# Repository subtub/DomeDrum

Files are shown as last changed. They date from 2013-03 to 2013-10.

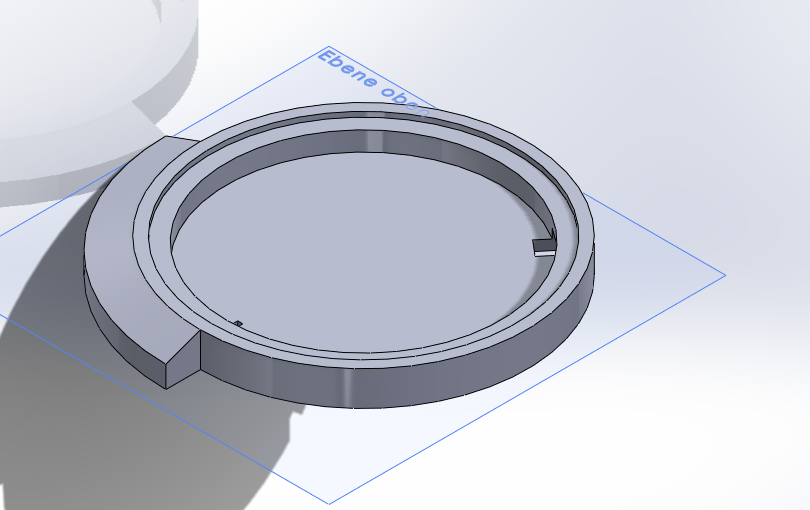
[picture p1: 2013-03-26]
Images/base_side_view.PNG

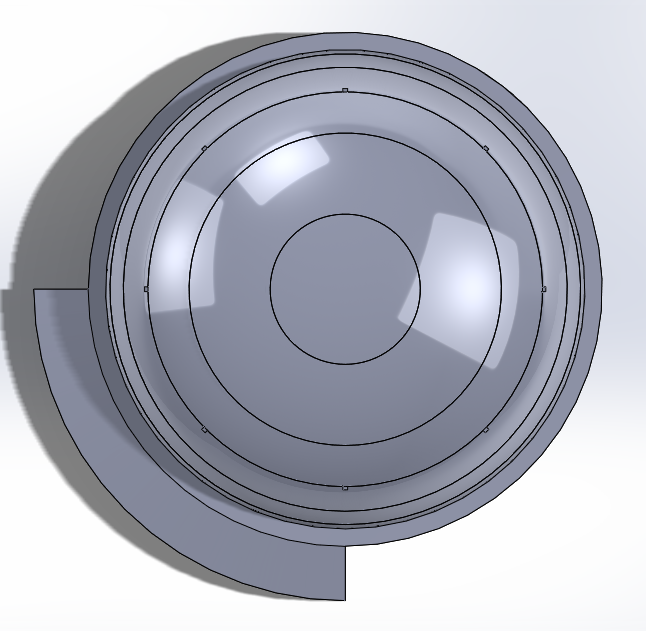
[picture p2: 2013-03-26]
Images/complete_top_view.PNG

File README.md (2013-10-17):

# DomeDrum

DomeDrum body image

**DomeDrum** is an open source MIDI controller.

Our aim of making the first version of **DomeDrum** was building a drum controller which feels like an analog drum. Did you ever play a [Djembe](http://en.wikipedia.org/wiki/Djembe)? It has one surface, depending on where you hit it the sound differs. We like pad-based controllers like the [MPC](http://en.wikipedia.org/wiki/Music_Production_Center), too but it's far away from an anlog drum. We wanted to brings that analog feeling back.

# DIY

We used an additional »head« made out of silicone on top of the wooden body for a softer feel while drumming. Use whatever you think feels good here.
To asseble your own DomeDrum you need to mill the wooden body, assemble the electronics and upload our Arduino software to a [Teensie Board](http://www.pjrc.com/teensy/).
Have a look at the [shopping list](https://github.com/subtub/DomeDrum/blob/master/Shopping_List.md) to see what's needed.

Bitdeli Badge (https://bitdeli.com/free "Bitdeli Badge")

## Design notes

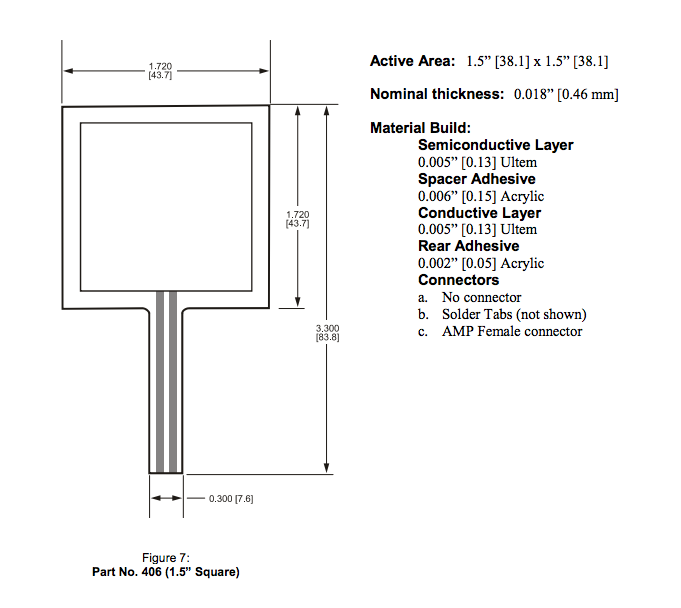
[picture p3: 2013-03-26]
Images/fsr-406_dimensions.png

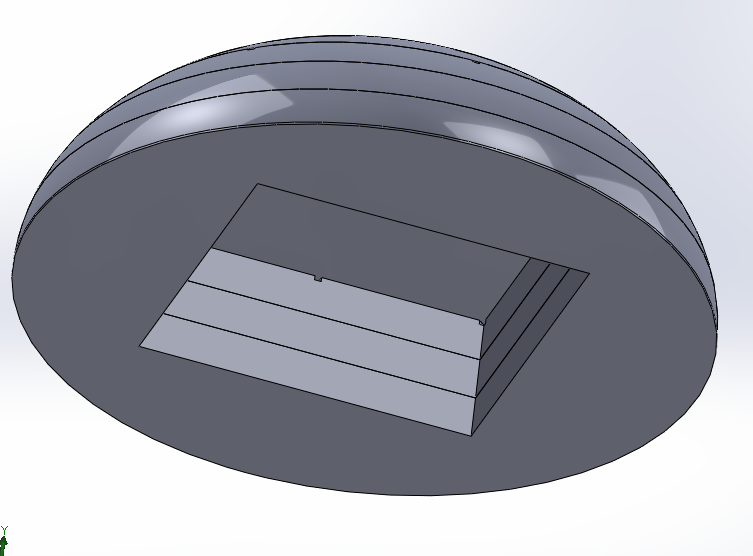
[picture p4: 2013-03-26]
Images/dome_bottom_view.PNG

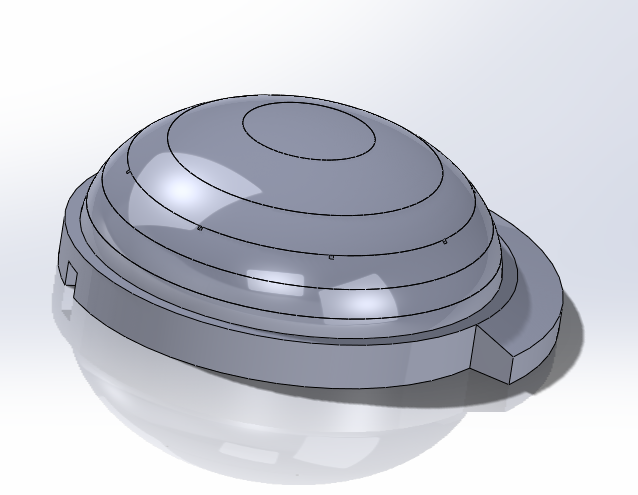
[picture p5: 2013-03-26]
Images/complete_side_view.PNG

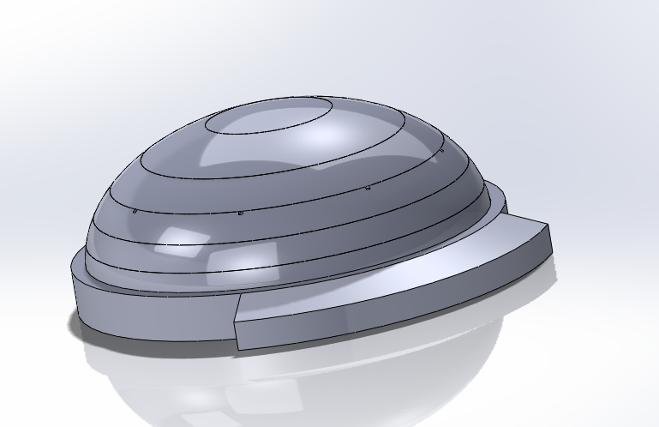
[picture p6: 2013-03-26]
Images/complete_side_view_2.PNG

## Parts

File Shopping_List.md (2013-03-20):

# Needed Parts

## FSR-406 Forse sensors × 9

image force sensor

~ [$72](https://www.adafruit.com/products/1075)

## Medium-density fiberboard (MDF)

mdf image

Material for the dome, will be glued together after milling, 600 × 700 × 19 mm

# Hevea wood sheet

helvea image

Used for the base plate, looks nicer than MDF. 400 × 400 × 36 mm

## Teensie 2.0 board

Teensie image

[$16](http://www.pjrc.com/store/teensy.html)

## Resistors

Have a look at the Fritzing file.

~ $1

## Silicone Spray

Used for the »head«, for a better drum feeling

silicone spray image

~ $7

## Pantyhose

To cover the silicone head

pantyhose image

~ $5

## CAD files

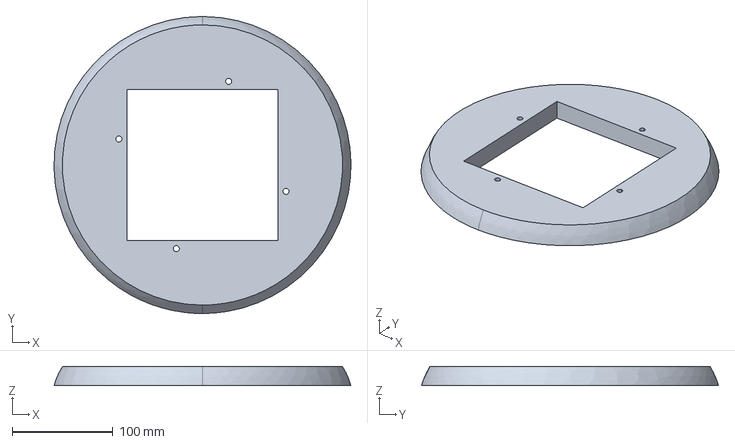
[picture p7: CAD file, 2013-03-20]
3d/step/dome01.STEP
294.9 x 295.0 x 19.0 mm

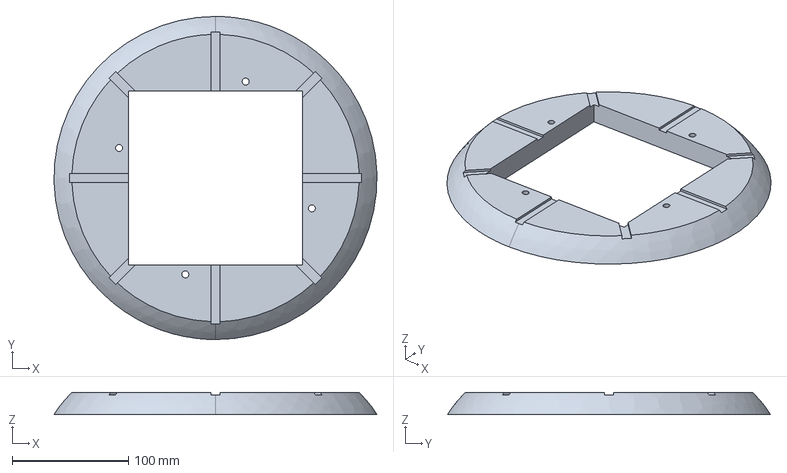
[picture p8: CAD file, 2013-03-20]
3d/step/dome03.STEP
278.2 x 278.3 x 19.0 mm

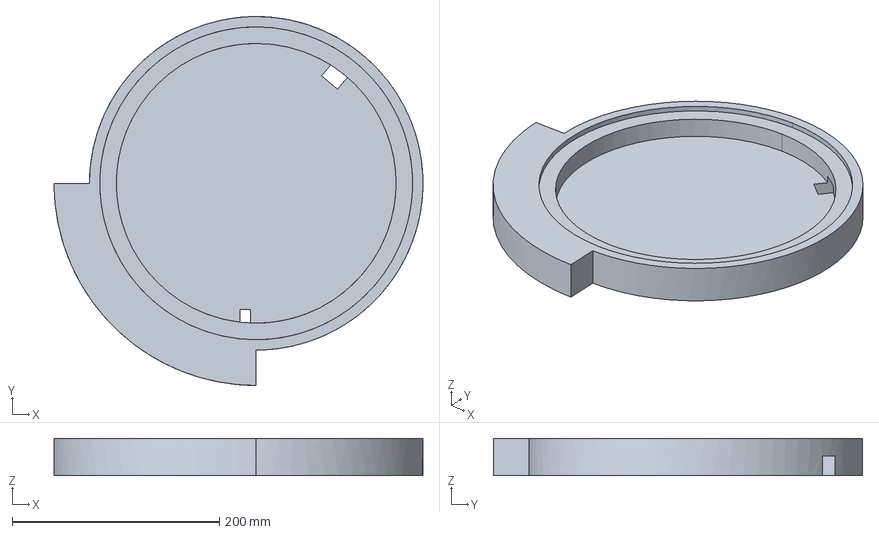
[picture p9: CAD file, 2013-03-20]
3d/step/domebase.STEP
356.1 x 356.2 x 36.0 mm

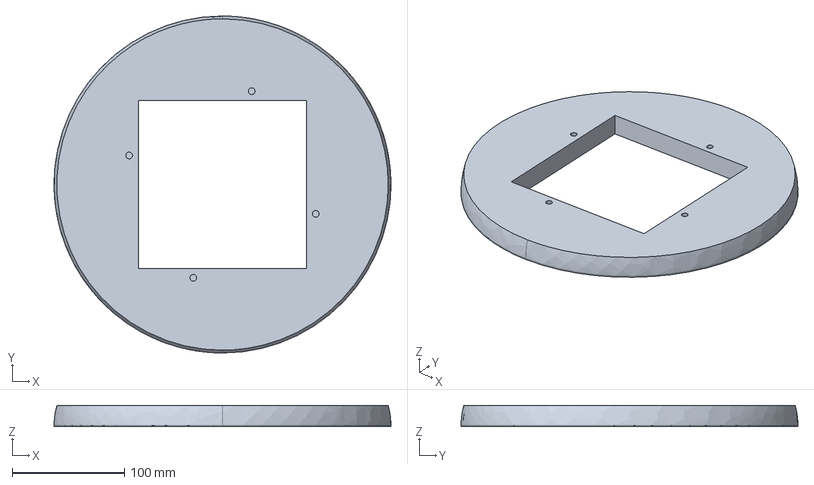
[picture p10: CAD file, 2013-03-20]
3d/step/dome05.STEP
300.0 x 300.0 x 19.0 mm

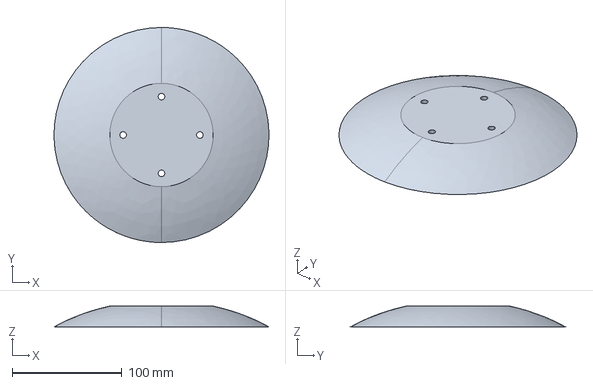
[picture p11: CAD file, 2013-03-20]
3d/step/dome04.STEP
195.8 x 195.8 x 19.0 mm

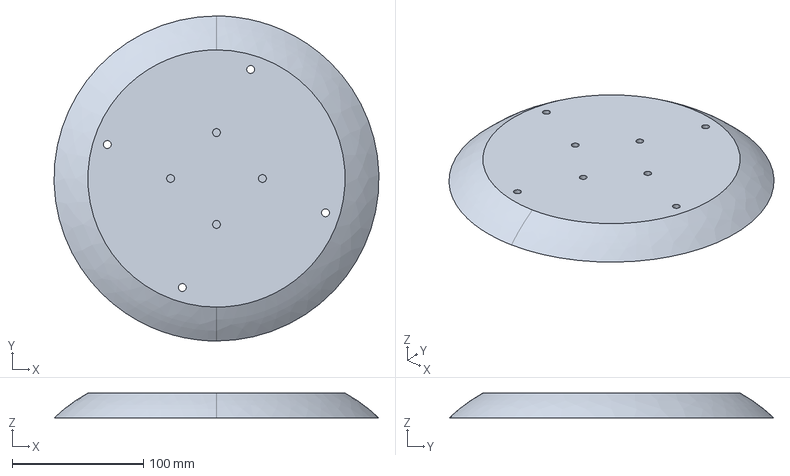
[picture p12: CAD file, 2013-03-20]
3d/step/dome02.STEP
247.3 x 247.4 x 19.0 mm

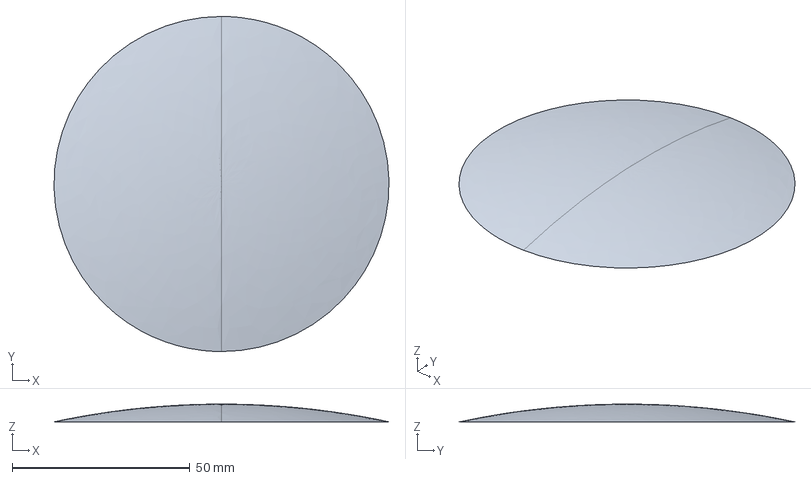
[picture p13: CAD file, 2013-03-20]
3d/step/dome06.STEP
94.1 x 94.1 x 5.00 mm

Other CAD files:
3d/igs/dome01.igs
3d/igs/dome02.igs
3d/igs/dome03.igs
3d/igs/dome04.igs
3d/igs/dome05.igs
3d/igs/dome06.igs
3d/igs/domebase.igs

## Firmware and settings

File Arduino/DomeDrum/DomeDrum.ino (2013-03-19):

/**
 * DomeDrum - DomeDrum.ino
 *
 * Hardware:   Teensy 2.0
 * Version:    0.0.1
 *
 *
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
 * You should have received a copy of the GNU General Public License
 * along with this program; if not, write to the Free Software Foundation,
 * Inc., 59 Temple Place, Suite 330, Boston, MA  02111-1307  USA
 */

#include "DomeDrumConstants.h"
#include "FSR.h"

FSR fsr[FSR_TOTAL];
boolean capSenseActive = true;

/**
 * Main setup
 */
void setup() {
  initDebugLed();
  initFsrs();
  if(capSenseActive){
    initCapSense();
  }
  Serial.begin(9600);
  Serial.println("hello");
}

/**
 * Initialize the LED debug pins
 */
void initDebugLed() {
  // declare LED as output
  pinMode(TEENSY_PIN_LED, OUTPUT);
  // declare pushbutton as input
  pinMode(TEENSY_PIN_BUTTON, INPUT);
}

/**
 * Initialize the FSR class array
 */
void initFsrs(){
  // We use Teensy Pins 12 - 21
  for(int i=0; i<FSR_TOTAL; i++){
    fsr[i].init(TEENSY_PIN_FSR_START+i, VELOCITY_DEF_THRESHOLD, MIDI_CHANNEL, MIDI_NOTE_START+i);
  }
}

/**
 * Main loop
 */
void loop() {
  loopDebugLed();
  loopFsrs();
  if(capSenseActive){
    capSenseUpdate();
  }
  delay(10);
}

/**
 * Turn on the LED if button is pressed
 */
void loopDebugLed() {
  // read input value
  int val = digitalRead(TEENSY_PIN_BUTTON);
  // check if the input is HIGH (button released)
  if (val == HIGH) {
    // Turn LED off
    digitalWrite(TEENSY_PIN_LED, LOW);
  } else {
    // Turn LED on
    digitalWrite(TEENSY_PIN_LED, HIGH);
  }
}

/**
 * Update all FSR sensors
 */
void loopFsrs() {
  for(int i=0; i<FSR_TOTAL; i++){
    fsr[i].updateMidiNote();
  }
}

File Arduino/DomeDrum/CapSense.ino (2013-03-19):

/**
 * DomeDrum - CapSense.ino
 *
 *
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
 * You should have received a copy of the GNU General Public License
 * along with this program; if not, write to the Free Software Foundation,
 * Inc., 59 Temple Place, Suite 330, Boston, MA  02111-1307  USA
 */

#include <CapSense.h>

/*
  Macbook Netzteil dran, sonst reagiert CapSense beim Tippern auf Laptop...
*/

int lastMappedVal = 0;

CapSense cs = CapSense(4, 6); // 2.7M resistor between pins 4 & 6, pin 6 is sensor pin, add a wire and or foil;

int max = 0;
long capBuffer[CAPSENSE_BUFFER_SIZE];
int capBufferCounter = 0;


void initCapSense() {
  initCapBuffer();
  //cs.set_CS_AutocaL_Millis(0xFFFFFFFF);     // turn off autocalibrate on channel 1
  cs.set_CS_AutocaL_Millis(10000);     // turn off autocalibrate on channel 1
}


void capSenseUpdate() {
  // read value
  long total1 =  cs.capSense(30);
  
  // store in buffer / reset buffer index // increment buffer
  if(capBufferCounter >= CAPSENSE_BUFFER_SIZE) capBufferCounter = 0;
  capBuffer[capBufferCounter] = total1;
  capBufferCounter++;
  
  // calculate average
  long avg = getAverage(capBuffer, CAPSENSE_BUFFER_SIZE);  
    
  int mappedCapVal = 0;
  //if(total1 < CAP_SENSE_THRESH){
  if(avg < CAP_SENSE_AVG_THRESH){
    mappedCapVal = 0;
  }
  else {
    //mappedCapVal = map(avg, CAP_SENSE_THRESH, 240, 0, 127);
    mappedCapVal = map(avg, CAP_SENSE_AVG_THRESH, 240, 0, 127);
    if(mappedCapVal > 127) mappedCapVal = 127;
  }
  Serial.print("CapSense: Value: ");
  Serial.print(total1);
  Serial.print("\tAverage: ");
  Serial.print(avg);
  Serial.print("\tMappedCapVal: ");
  Serial.print(mappedCapVal);
  Serial.print("\n");
  
  //usbMIDI.sendNoteOn(100, mappedCapVal, 1);
  //usbMIDI.sendControlChange(CAP_SENSE_MIDI_NOTE, mappedCapVal, CAP_SENSE_MIDI_CHANNEL);
  //usbMIDI.sendPitchBend(mappedCapVal, CAP_SENSE_MIDI_CHANNEL);
  //usbMIDI.sendPitchBend(0x2000 + mappedCapVal, CAP_SENSE_MIDI_CHANNEL);
  int capSenseTolerance = 3;
  //if(lastMappedVal != mappedCapVal){
    if(mappedCapVal > lastMappedVal + capSenseTolerance || mappedCapVal < lastMappedVal - capSenseTolerance){
    usbMIDI.sendControlChange(CAP_SENSE_MIDI_NOTE, mappedCapVal, CAP_SENSE_MIDI_CHANNEL);
  }
  
}


long getAverage(long arr[], int arraySize){
  long sum = 0;
  for(int i=0; i<arraySize; i++){
    sum += arr[i];
  }
  return sum / arraySize;
}

void initCapBuffer(){
  for(int i=0; i<CAPSENSE_BUFFER_SIZE; i++){
    capBuffer[i] = 0;
  }
}

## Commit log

2013-01-30 Added hardware Fritzing file
    [DomeDrum.fzz]
2013-01-31 Rename Arduino sketch to DomeDrum
2013-02-02 remove midi bug at loop
    [DomeDrum.ino]
2013-02-03 Wert begrenzt zwischen 0 und 127.. geht gut
2013-03-20 Renamed Hardware dir
    [DomeDrum.fzz]
2013-03-20 Added 3d files
    [dome01.STEP, dome01.igs, dome02.STEP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]
2013-03-20 Renamed Software to Arduino
2013-03-20 Moved arduino files

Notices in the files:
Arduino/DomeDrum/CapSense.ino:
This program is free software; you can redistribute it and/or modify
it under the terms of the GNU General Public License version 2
